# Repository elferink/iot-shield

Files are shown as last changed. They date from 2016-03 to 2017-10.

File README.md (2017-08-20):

# WeMos IoT shield

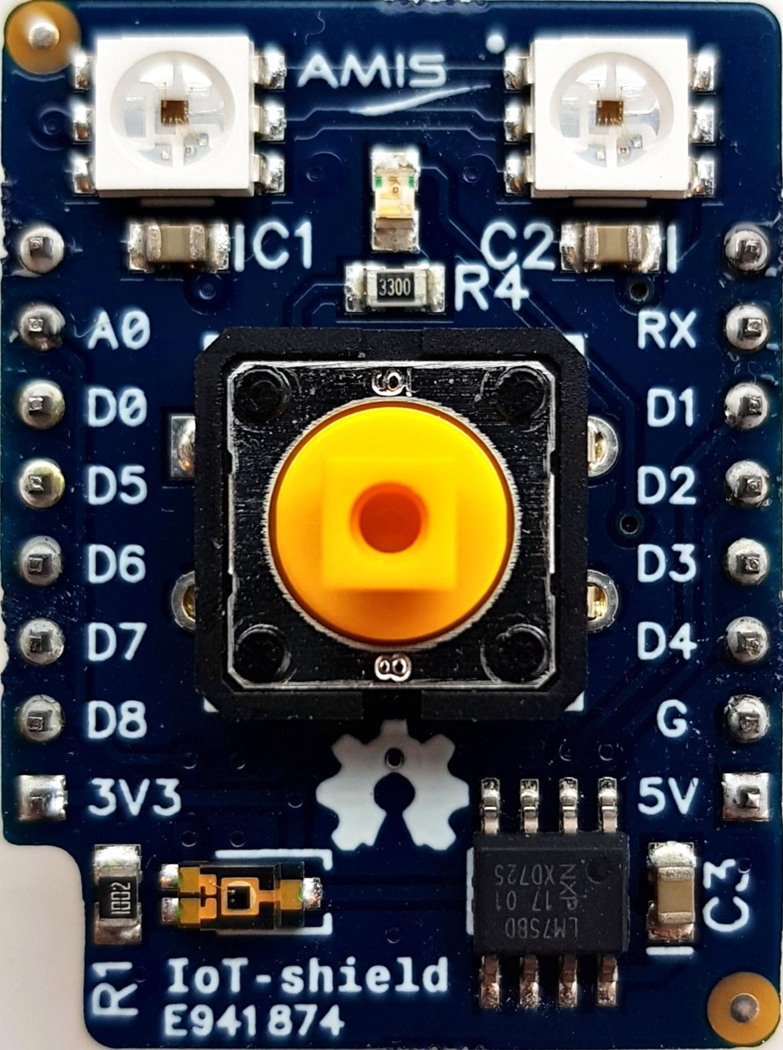
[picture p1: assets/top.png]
top
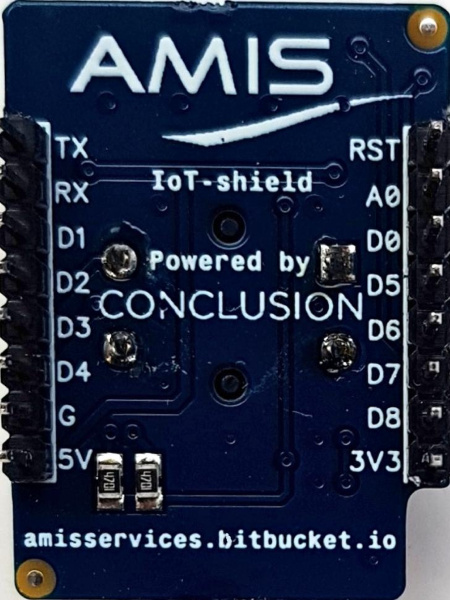
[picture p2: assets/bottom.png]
bottom


## Features

* Ambient Light Sensor ([TEMT6000X01](http://www.vishay.com/docs/81579/temt6000.pdf))
* Digital temperature sensor ([LM75B](http://www.nxp.com/documents/data_sheet/LM75B.pdf))
* Two [APA102C](https://cpldcpu.files.wordpress.com/2014/08/apa-102c-super-led-specifications-2014-en.pdf) RGB LED
* Yellow LED ([APT2012YC](http://www.kingbrightusa.com/images/catalog/SPEC/APT2012YC.pdf))
* Pushbutton Switch [B3F-4055](https://www.omron.com/ecb/products/pdf/en-b3f.pdf)

## Reference
| Shield | [WeMos D1 Mini](http://www.wemos.cc/wiki/doku.php?id=en:d1_mini#diagram) | [ESP8266 Arduino Core](https://github.com/esp8266/Arduino) |
|---|---|---|
| TEMT6000X01| A0 | ADC |
| nc | D0 | D16~ |
| LM75B SCL  | D1 | D5~ SCL |
| LM75B SDA  | D2 | D4~ SDA |
| Button | D3 | D0~ |
| Yellow LED | D4 | D2~ |
| APA102 SCK | D5 | D14~ SCK |
| nc | D6 | D12~ MISO |
| APA102 MOSI| D7 | D13~ MOSI |
| nc | D8 | D15~ SS |

## Hardware design
Hardware design by Bart Schapendonk, Jeroen Idserda en Thijs Elferink.
See original files: https://github.com/topicusonderwijs/iota

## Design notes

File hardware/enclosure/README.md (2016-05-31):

## Enclosure

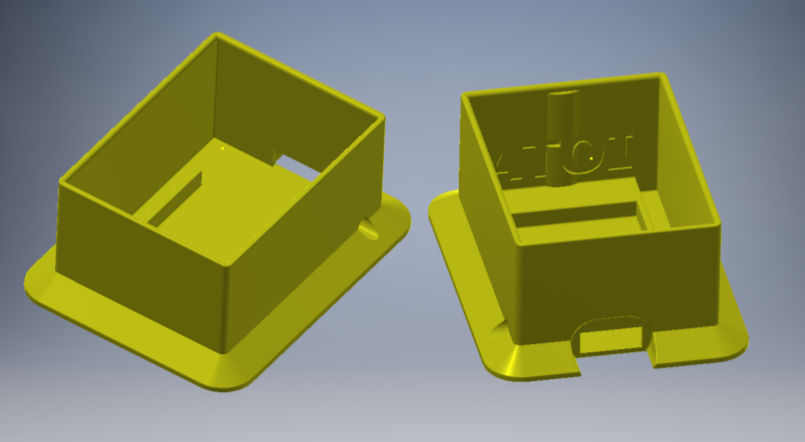
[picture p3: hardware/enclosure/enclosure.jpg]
Enclosure


Use the STL-file in this directory to print your own enclosure.

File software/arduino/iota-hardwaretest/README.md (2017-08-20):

Sketch voor hardware test:

On powerup brand de (gewone) gele led als de lichtsensor een klein beetje licht detecteert, als je hem verduistert gaat de led uit (hand er boven of vinger er op).
On powerup branden de RGB leds roze als de temperatuursensor een geldige waarde weergeeft.
Als je op de knop drukt dan cyclen de RGB leds tussen R, G, B en uit. Elke waarde een seconde.

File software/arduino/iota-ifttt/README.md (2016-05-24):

# IFTTT

This Arduino sketch connects the button on the IoTa board to  the IFTTT Maker channel. 

## Dependencies

* OneButton Library: https://github.com/mathertel/OneButton

## Usage

* Create IFTTT account
* Edit sketch to use correct wifi ssid & password
* Connect Maker channel: https://ifttt.com/maker 
* Create recipe
* Copy IFTTT channel key into sketch
* Compile & Upload

See [this tutorial](http://bigjungle.net/blog/2015/6/26/connect-maker-to-anything-ifttt) for more information.

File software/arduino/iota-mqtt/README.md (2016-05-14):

# MQTT & openHAB sketch

This Arduino sketch makes all functionality of the board available through MQTT. This can then be used in openHAB. 



## Dependencies

* Arduino Client for MQTT: https://github.com/knolleary/pubsubclient
* LM75 Arduino Library: https://github.com/thefekete/LM75
* FastLED library: https://github.com/FastLED/FastLED

## Topics

Format: ```actuator/<mac>/<item>```

| Topic | Values | Mode | Description |
|---|---|---|---|
| actuator/18-FE-00-01-02-03/state | ON or OFF | Read | Device connected to mqtt server |
| actuator/18-FE-00-01-02-03/light | 0 to 660 | Read | Amount of light, in lux |
| actuator/18-FE-00-01-02-03/temperature | -55 to 125 | Read  |Temperature, in degrees Celsius |
| actuator/18-FE-00-01-02-03/button | ON | Read | Switch button pressed |
| actuator/18-FE-00-01-02-03/led | ON or OFF | Write |Controls the onboard led |
| actuator/18-FE-00-01-02-03/rgb/0 | h,s,v (0-360,0-100,0-100) | Write | Controls first RGB led |
| actuator/18-FE-00-01-02-03/rgb/1 | h,s,v (0-360,0-100,0-100) | Write | Controls second RGB led |
 
## openHAB 

Configure openHAB with the [MQTT binding](https://github.com/openhab/openhab/wiki/MQTT-Binding). Name of the broker = 'home' in this example. 

**Items**

```
Number 	Iota_Temperature	"Temperature [%.1f °C]" <temperature>	{mqtt="<[home:actuator/18-FE-00-01-02-03/temperature:state:default]"}
Number 	Iota_Light			"Light [%.1f lux]"  	<sun>			{mqtt="<[home:actuator/18-FE-00-01-02-03/light:state:default]"}
Switch	Iota_Button			"Button [%s]" 	  						{mqtt="<[home:actuator/18-FE-00-01-02-03button:state:default]"}

Color	Iota_Rgb0			"RGB led 0" 			<hue>  			{mqtt=">[home:actuator/5c-cf-7f-10-7e-2d/rgb/0:command:*:default]"}
Color 	Iota_Rgb1			"RGB led 1" 			<hue>   		{mqtt=">[home:actuator/5c-cf-7f-10-7e-2d/rgb/1:command:*:default]"}

Switch 	Iota_Led			"Led"  					<switch>		{mqtt=">[home:actuator/18-FE-00-01-02-03led:command:*:default]"}

``` 

**Sitemap**

```
sitemap iota label="iota"
{
	Frame {
		Text item=Iota_Button
		Switch item=Iota_Led
		Colorpicker item=Iota_Rgb0
		Colorpicker item=Iota_Rgb1
		Text item=Iota_Light
		Text item=Iota_Temperature
	}
}
```

**Rules**

```
import org.openhab.core.library.types.*
import java.awt.Color

rule "iota button"
when
	Item Iota_Button received update ON 
then
	sendCommand(Toggle_Lamp, ON)
end
```

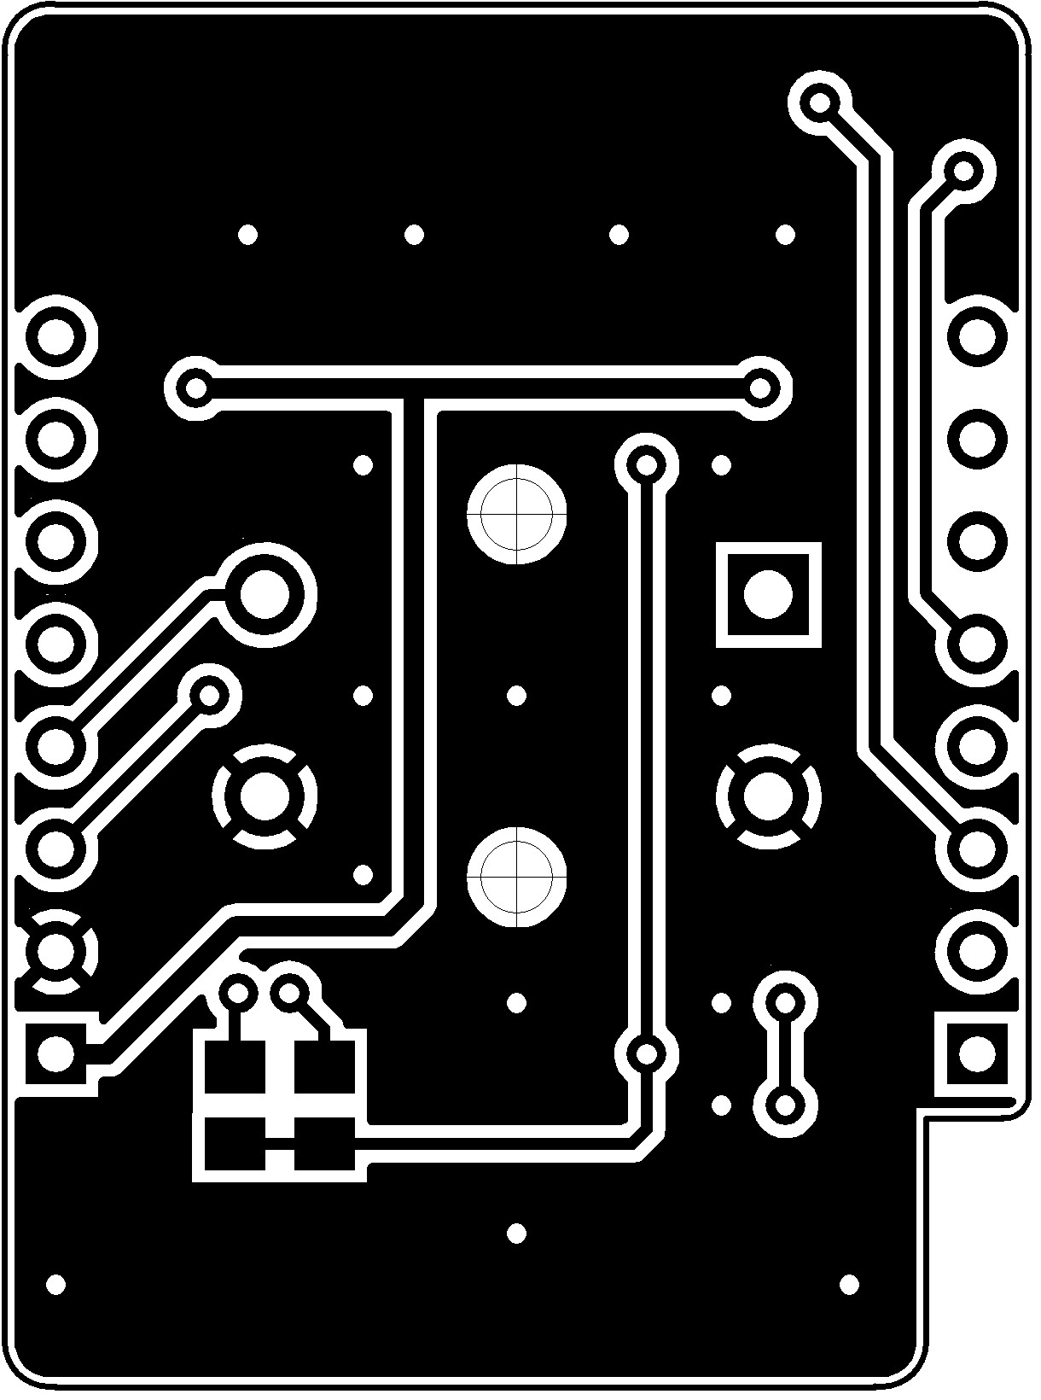
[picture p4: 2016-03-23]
hardware/pdf/bottom.jpg

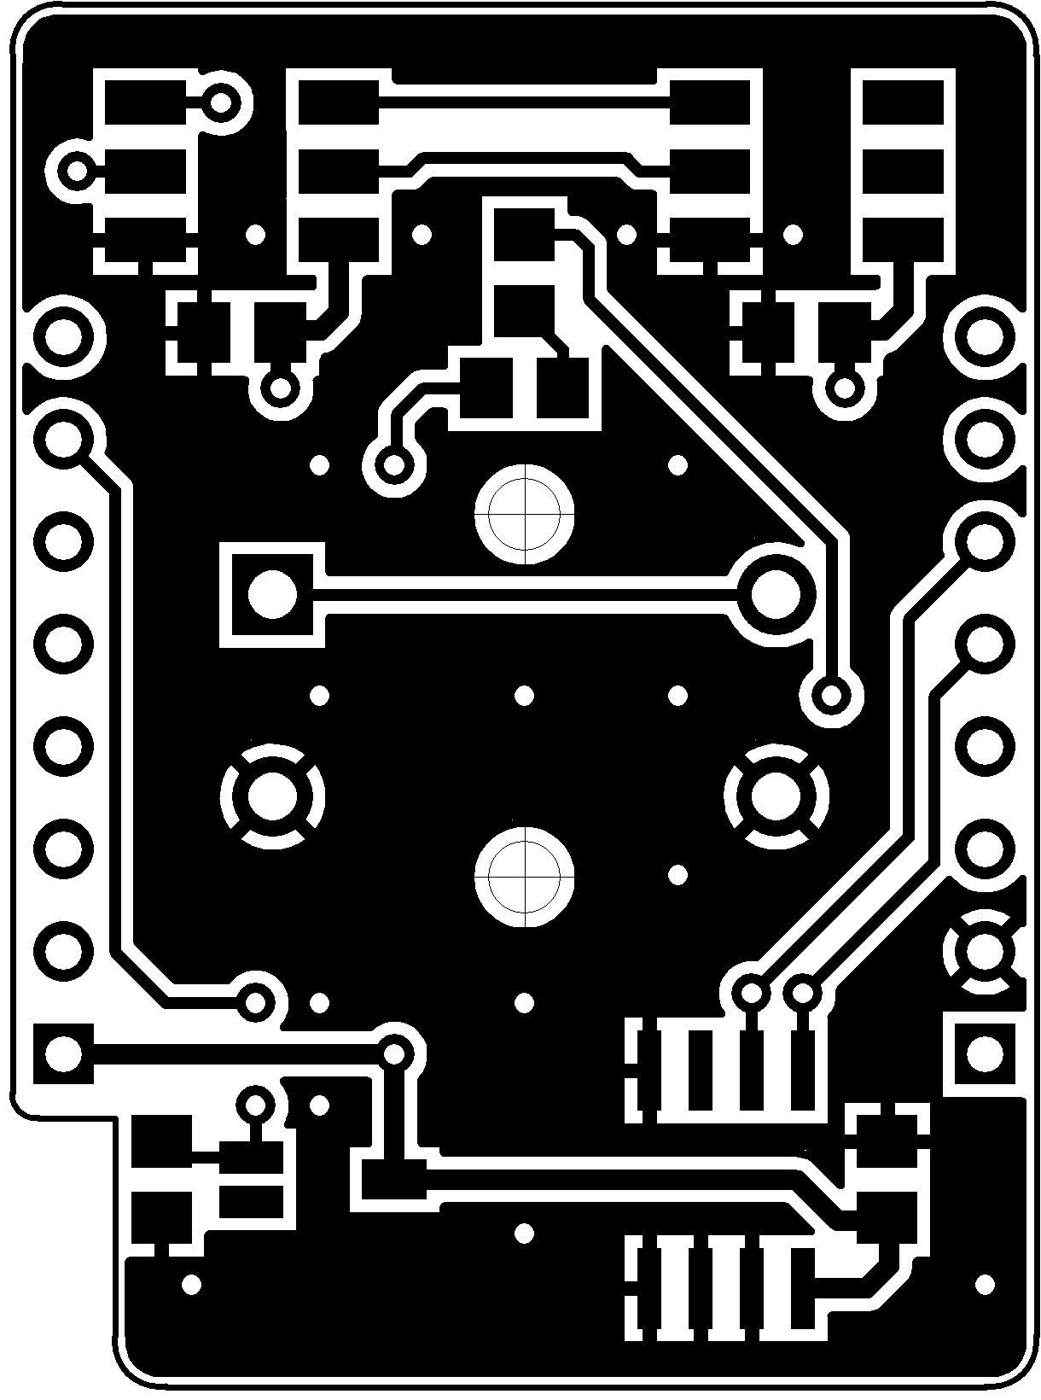
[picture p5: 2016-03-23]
hardware/pdf/top.jpg

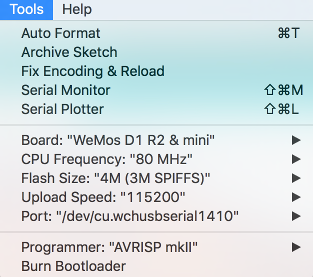
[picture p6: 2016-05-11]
assets/settings-tools.png

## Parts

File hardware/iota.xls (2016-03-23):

iota
Mouser No | Mfr. # | Manufacturer | Desc. | RoHS | Lifecycle | Customer Part No. | Order Qty. | Price (EUR) | Ext: (EUR)
653-B3F-4055 | B3F-4055 | Omron | Tactile Switches 12x12mm Std Ht .3 High-force 260g | RoHS Compliant |  |  | 1 | € 0,371 | € 0,37
667-ERJ-6ENF3300V | ERJ-6ENF3300V | Panasonic | Thick Film Resistors - SMD 0805 330ohms 1% AEC-Q200 | RoHS Compliant By Exemption |  |  | 1 | € 0,091 | € 0,09
667-ERJ-6ENF4701V | ERJ-6ENF4701V | Panasonic | Thick Film Resistors - SMD 0805 4.7Kohms 1% AEC-Q200 | RoHS Compliant By Exemption |  |  | 2 | € 0,091 | € 0,18
771-LM75BD118 | LM75BD,118 | NXP | Board Mount Temperature Sensors I2C LOCAL +/- 20C TS DIGITAL TEMP SENSOR | RoHS Compliant |  |  | 1 | € 0,525 | € 0,53
581-08055C104K | 08055C104KAT2A | AVX | Multilayer Ceramic Capacitors MLCC - SMD/SMT 0805 0.1uF 50volts X7R 10% | RoHS Compliant By Exemption |  |  | 3 | € 0,091 | € 0,27
667-ERJ-6ENF1002V | ERJ-6ENF1002V | Panasonic | Thick Film Resistors - SMD 0805 10Kohms 1% AEC-Q200 | RoHS Compliant By Exemption |  |  | 1 | € 0,10 | € 0,10
604-APT2012YC | APT2012YC | Kingbright | Standard LEDs - SMD YELLOW WATER CLEAR | RoHS Compliant |  |  | 1 | € 0,128 | € 0,13
78-TEMT6000 | TEMT6000X01 | Vishay | Ambient Light Sensors Ambient Light Sensor AEC-Q101 Qualified | RoHS Compliant |  |  | 1 | € 1,20 | € 1,20

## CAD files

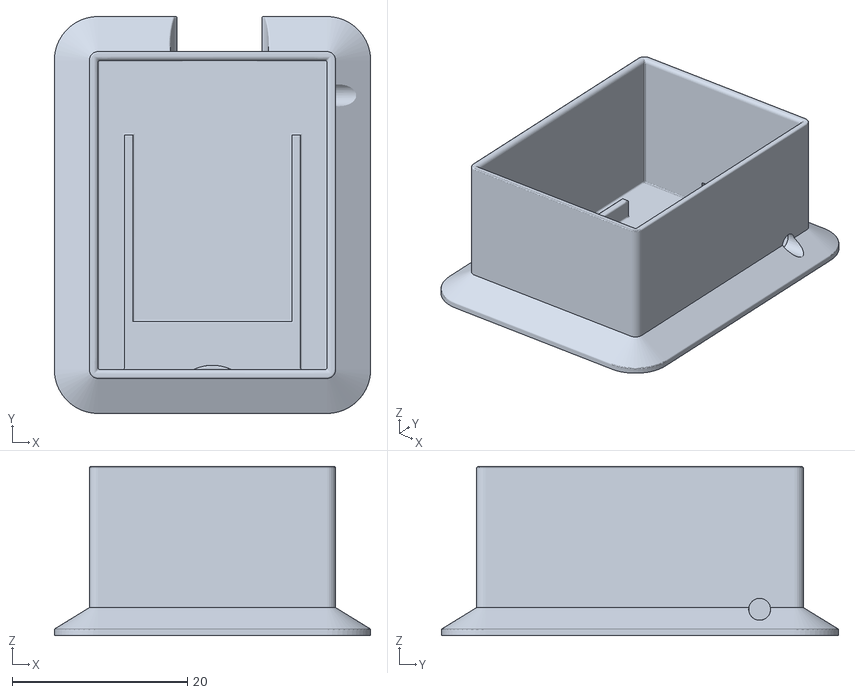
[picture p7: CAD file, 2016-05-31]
hardware/enclosure/iota-enclosure.stl
36.1 x 45.3 x 19.3

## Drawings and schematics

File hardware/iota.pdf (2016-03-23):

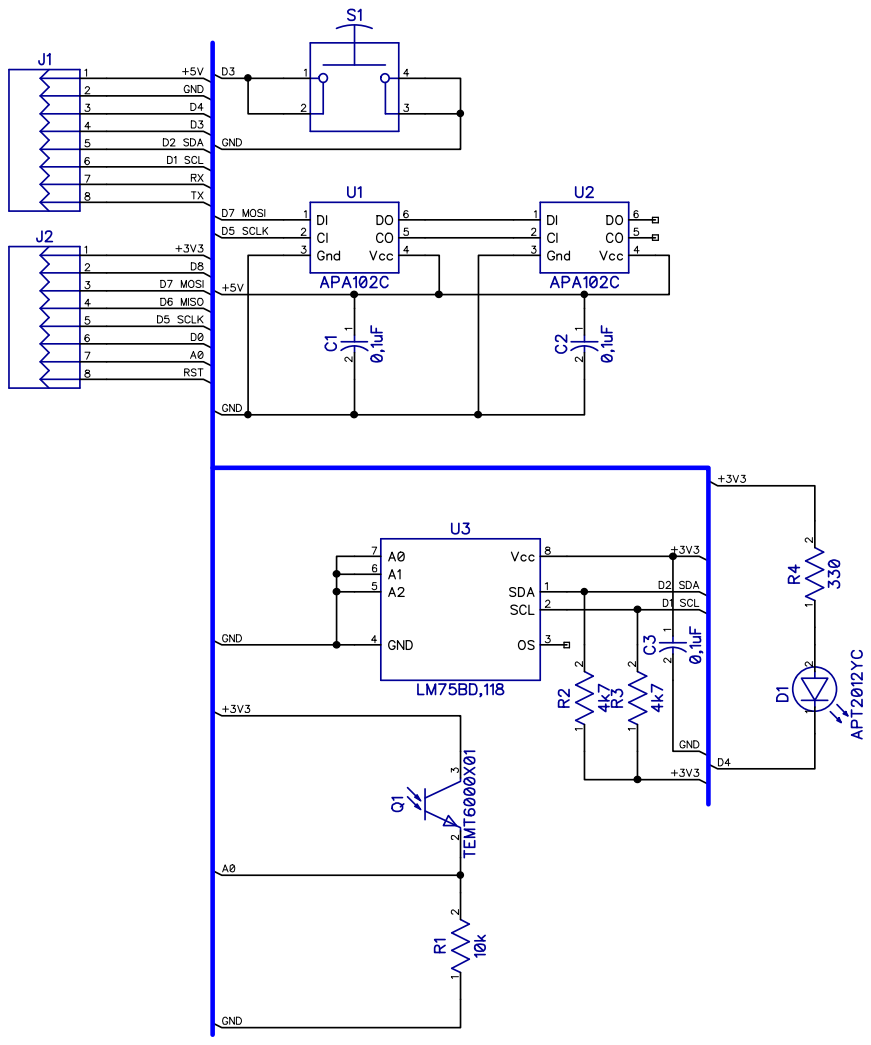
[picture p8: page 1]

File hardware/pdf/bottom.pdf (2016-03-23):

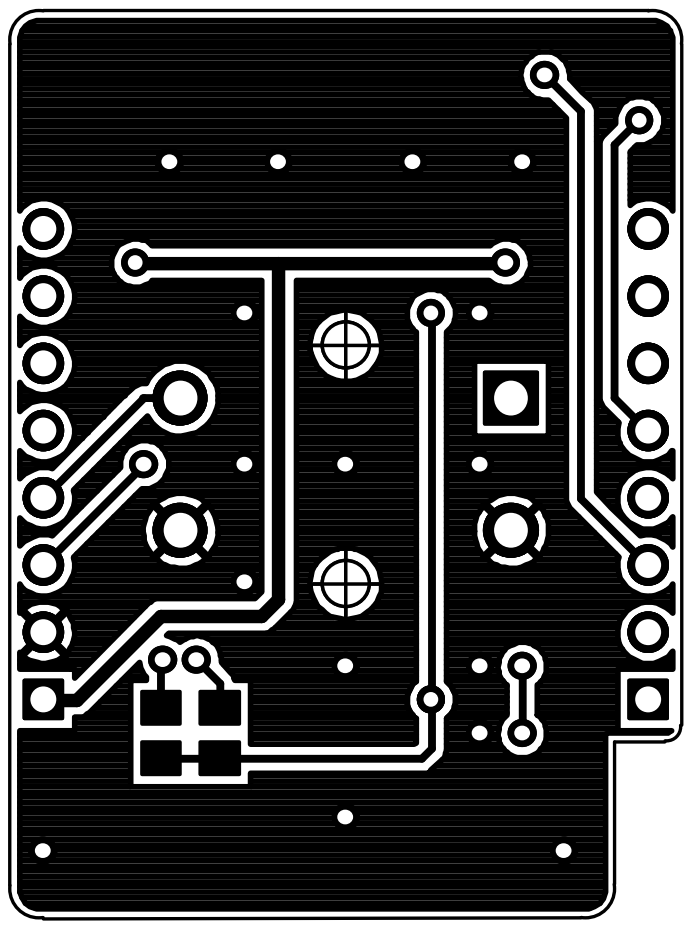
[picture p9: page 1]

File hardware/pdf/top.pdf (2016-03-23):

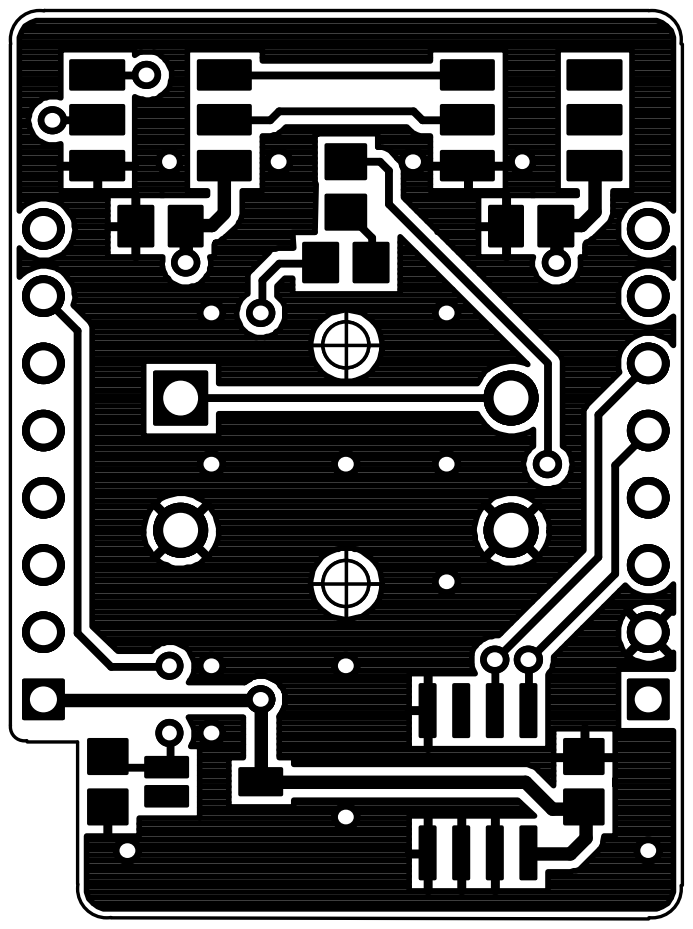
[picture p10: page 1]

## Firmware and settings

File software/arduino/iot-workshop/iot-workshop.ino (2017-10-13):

#include <ESP8266WiFi.h>
#include "OneButton.h"
#include <Wire.h>
#include <LM75.h>
#include <FastLED.h>

/*
   Constanten
*/
#define WIFI_SSID           "iot-workshop"
#define WIFI_PASSWORD       "123456ab"

#define BUTTON_PIN          0   // D3
#define LED_PIN             2   // D4

#define RGB_LED_BRIGHTNESS  10 // 0-255
#define RGB_LED_DATA_PIN    13  // D7
#define RGB_LED_CLOCK_PIN   14  // D5
#define RGB_NUM_LEDS        2
#define RGB_LED_TYPE        APA102
#define RGB_COLOR_ORDER     BGR

/*
     Runtime variabelen
*/
OneButton button(BUTTON_PIN, true);
LM75 temp_sensor;
CRGB leds[RGB_NUM_LEDS];
WiFiClient espClient;

boolean led_on = false;
boolean rgb_leds_on = false;
boolean cycle = false;
short cycle_idx = 0;
CRGB cycle_arr[] = {CRGB::Red, CRGB::Green, CRGB::Blue, CRGB::Black};

/*
   Functies om gebruik van de knop af te handelen
*/
void singleClick() {
  cycle = !cycle;
}

void doubleClick() {
  singleClick();
}

void longPress() {
  readSensors();
}

/*
   Temperatuursensor
*/
float getTemperature() {
  // Sensor activeren
  temp_sensor.shutdown(false);
  delay(100);

  float temperature = temp_sensor.temp();

  // Sensor deactiveren
  temp_sensor.shutdown(true);

  return temperature;
}

/*
   Lichtsensor
*/
float getLuminance() {
  // Meet voltage op analoge input en reken dit om in het equivalente aantal lux
  float volts = analogRead(A0) * 3.3 / 1024.0;
  float amps = volts / 10000.0;  // 10k weerstand
  float microamps = amps * 1000000;
  float lux = microamps * 2.0;

  return lux;
}

/*
   Lees sensoren uit
*/
void readSensors() {
  Serial.print("Temperatuur: ");
  Serial.print(getTemperature());
  Serial.println("°C");

  Serial.print("Hoeveelheid licht: ");
  Serial.print(getLuminance());
  Serial.println(" lux");
}

/*
   Reguliere led
*/
void setLed(bool state) {
  digitalWrite(LED_PIN, !state);
}

/*
   RGB leds
*/
void setRgbLeds(CRGB color) {
  for (int i = 0; i < RGB_NUM_LEDS; i++) {
    setRgbLed(i, color);
  }
}

void setRgbLed(int ledno, CRGB color) {
  leds[ledno] = color;
  FastLED.show();
}

/*
   Deze functie wordt eenmalig aangroepen bij opstarten
*/
void setup() {
  Serial.begin(115200);
  delay(10);
  Serial.println();

  // Knop instellen
  pinMode(BUTTON_PIN, INPUT);
  button.setClickTicks(300);
  button.setPressTicks(600);
  button.attachClick(singleClick);
  button.attachDoubleClick(doubleClick);
  button.attachLongPressStart(longPress);

  // Start I2C voor temperatuursensor
  Wire.begin();

  // Reguliere led instellen
  pinMode(LED_PIN, OUTPUT);
  setLed(false); // led uit

  // Initialiseer RGB leds
  FastLED.addLeds<RGB_LED_TYPE, RGB_LED_DATA_PIN, RGB_LED_CLOCK_PIN, RGB_COLOR_ORDER>(leds, RGB_NUM_LEDS).setCorrection(TypicalLEDStrip);
  FastLED.setBrightness(RGB_LED_BRIGHTNESS);
  setRgbLeds(CRGB::Black); // beide leds uit

  // Wifi instellen
  WiFi.mode(WIFI_STA);
  WiFi.begin(WIFI_SSID, WIFI_PASSWORD);
  Serial.println(WiFi.hostname());
  Serial.print("Wifi verbinden");

  // Wachten tot wifi verbonden is
  while (WiFi.status() != WL_CONNECTED) {
    delay(200);
    Serial.print(".");
  }

  Serial.println(" verbonden!");
  Serial.print("IP: ");
  Serial.println(WiFi.localIP());
   
  // Lees beide sensoren uit
  readSensors();
}

/*
   Functie wordt continue aangroepen, voeg hier je eigen logica aan toe
*/
void loop() {
  // Laat knop controleren of er activiteit geweest is
  button.tick();
  if(getLuminance() > 40 ) {
    led_on = true;
  }
  else
  {
    led_on = false;
  }
  setLed(led_on);

  EVERY_N_SECONDS(1) {
    if(cycle) {
      setRgbLeds(cycle_arr[cycle_idx]);
      cycle_idx++;
      if(cycle_idx>3) {
        cycle_idx=0;
      }
    }
  }
}

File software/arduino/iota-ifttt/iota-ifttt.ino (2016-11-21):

#include <LM75.h>
#include <Wire.h>

#include <ESP8266HTTPClient.h>
#include <ESP8266WiFi.h>
#include "OneButton.h"

#define WIFI_SSID           "My Wifi"
#define WIFI_PASSWORD       "My Password"

#define IFTTT_URL           "http://maker.ifttt.com"
#define IFTTT_KEY           "IFTTT KEY";
#define IFTTT_EVENT         "IFTTT EVENT NAME";

#define BUTTON_PIN          0   // D3
OneButton button(BUTTON_PIN, true);
LM75 temp_sensor;

float getTemperature() {
  temp_sensor.shutdown(false);
  delay(100);
  float temperature = temp_sensor.temp();
  temp_sensor.shutdown(true);
  return temperature;
}

void setup() {
  Serial.begin(115200);
  delay(10);
  Serial.println();

  Wire.begin();

  WiFi.mode(WIFI_STA);
  WiFi.begin(WIFI_SSID, WIFI_PASSWORD);
  Serial.print("Connecting wifi");

  while (WiFi.status() != WL_CONNECTED) {
    delay(500);
    Serial.print(".");
  }

  Serial.println(" connected!");
  Serial.print("IP: ");
  Serial.println(WiFi.localIP());

  pinMode(BUTTON_PIN, INPUT);
  button.attachClick(singleClick);
}

void loop() {
  button.tick();
}

void singleClick() {
  String url;
  url += IFTTT_URL;
  url += "/trigger/";
  url += IFTTT_EVENT;
  url += "/with/key/";
  url += IFTTT_KEY;
  url += "?value1=";
  url += String(getTemperature());

  HTTPClient http;
  http.begin(url); 
  
  int httpCode = http.GET();
  if(httpCode == 200) {
    Serial.println("IFTTT OK");
  } else {
    Serial.print(httpCode);
    Serial.println("IFTTT FAIL");
  }

  http.end();
}

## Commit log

2016-03-18 inital import
    [iota.xls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]
2016-03-18 inital scaffolding for an post assembly shield test programm
    [iota.xls]
2016-03-18 disconnected the bottom pad of the temt6000
    [iota.GBL, iota.GTL, iota.GTO]
2016-03-18 updated all outputs
    [iota.GBL, iota.GBO, iota.GTL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]
2016-03-20 MQTT Arduino sketch
2016-03-21 removed LM75B OS output to D0, since D0 (GPIO16) has no interrupt support
    [iota.GBL, iota.GTL, iota.GTO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]
2016-03-21 replaced IOT vector by normal text
    [iota.GBL, iota.GTL, iota.GTO]
2016-03-23 fixed TEMT6000 footprint
    [iota.GBL, iota.GBO, iota.GTL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]
2016-03-23 use an B3F-4055 TH switch
    [iota.GBL, iota.GBO, iota.GBS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]
2016-03-23 update all outputs
    [iota.xls]
2016-03-23 silkscreen updated
    [iota.GBO, iota.GTO]
2016-03-29 Revert "test sketch"
    This reverts commit a6d42133827b9e4efbf9c1bcf2d223f3ad8e147a.
    [a_wifi.ino, apa.ino, iota-test.ino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]
2016-05-11 mqtt sketch: delay voor uitlezen temperatuur
2016-05-13 test sketch: fix build
    [z_report.ino]
2016-05-14 Kleine fixes workshop sketch
    [iota-workshop.ino]
2016-05-25 Fixed typo in iota-workshop.ino
    [iota-workshop.ino]
2016-05-31 Behuizing toegevoegd
    [iota-enclosure.stl]
2016-10-24 Jenkins sketch compatible met 2 jobs, 1 short press + 1 long press
    [apa.ino, button.ino, iota-jenkins-demo.ino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]
2016-11-21 Update IFTTT-sketch: temperatuur versturen
